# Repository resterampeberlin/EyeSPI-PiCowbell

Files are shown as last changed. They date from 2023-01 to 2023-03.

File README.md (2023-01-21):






              
# Purpose

# Credits

This open source code project is has been proudfully produced in Berlin (and other places around the globe) by

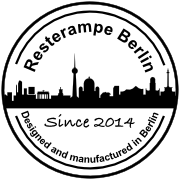
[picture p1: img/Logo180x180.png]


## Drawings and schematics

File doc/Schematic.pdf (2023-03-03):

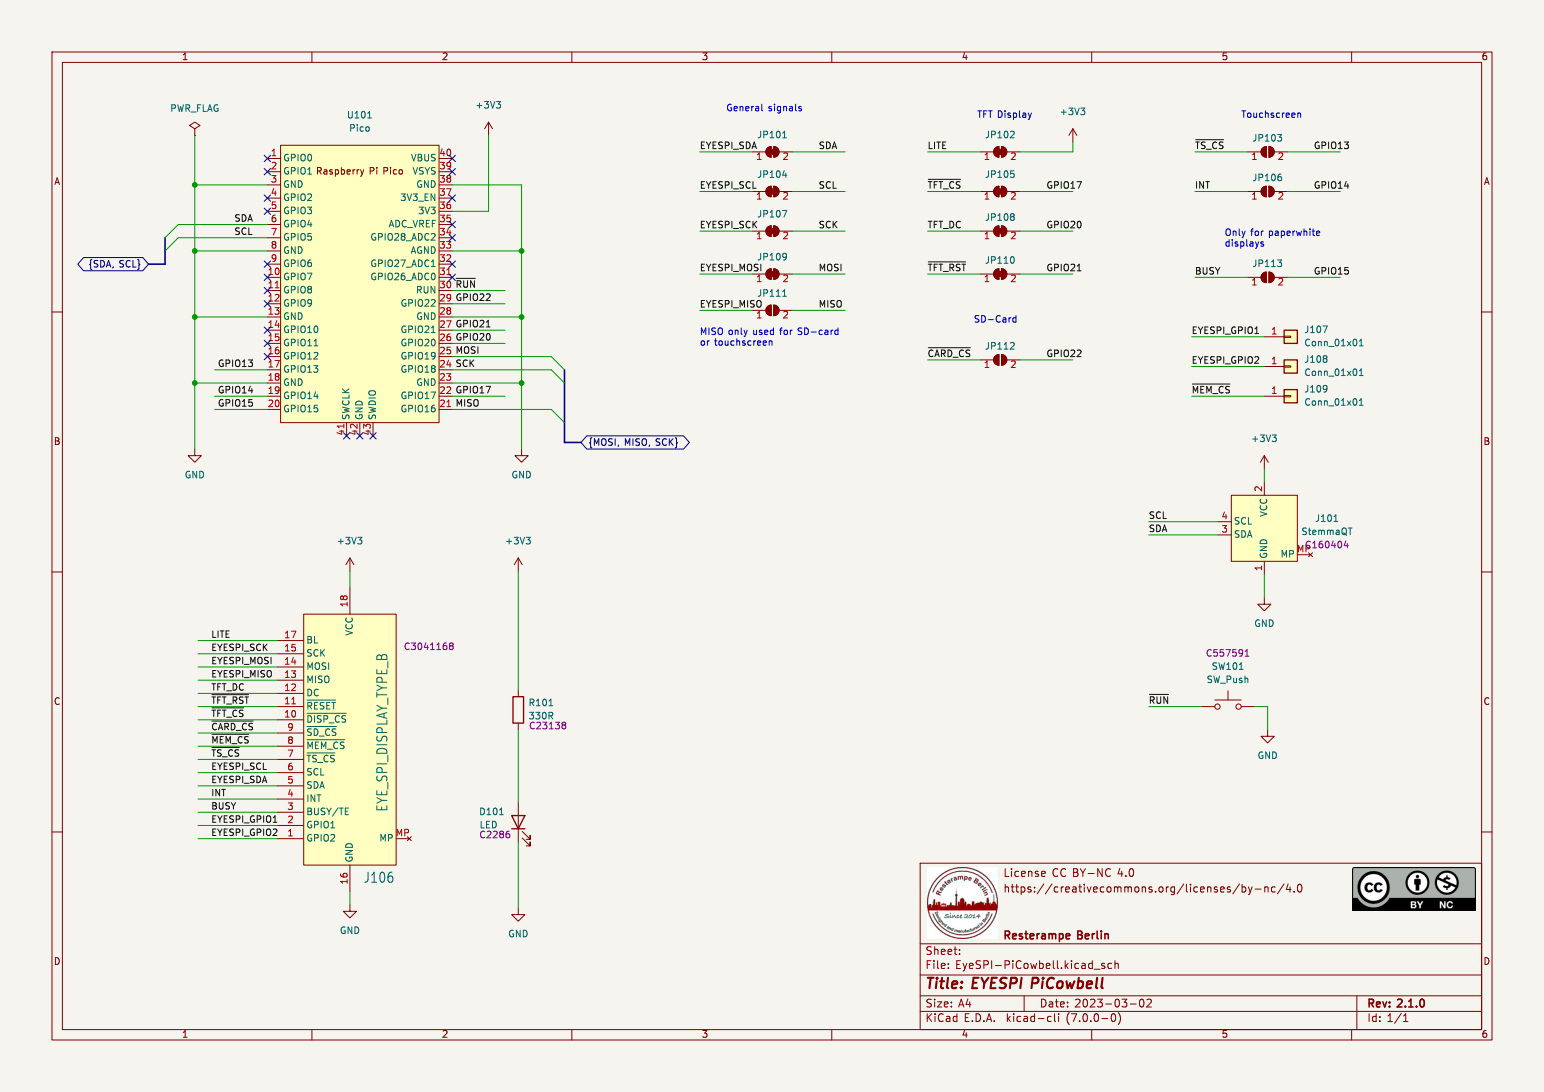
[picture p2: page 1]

2 SDA 3 SCL 4 MP MP

https://creativecommons.org/licenses/by-nc/4.0

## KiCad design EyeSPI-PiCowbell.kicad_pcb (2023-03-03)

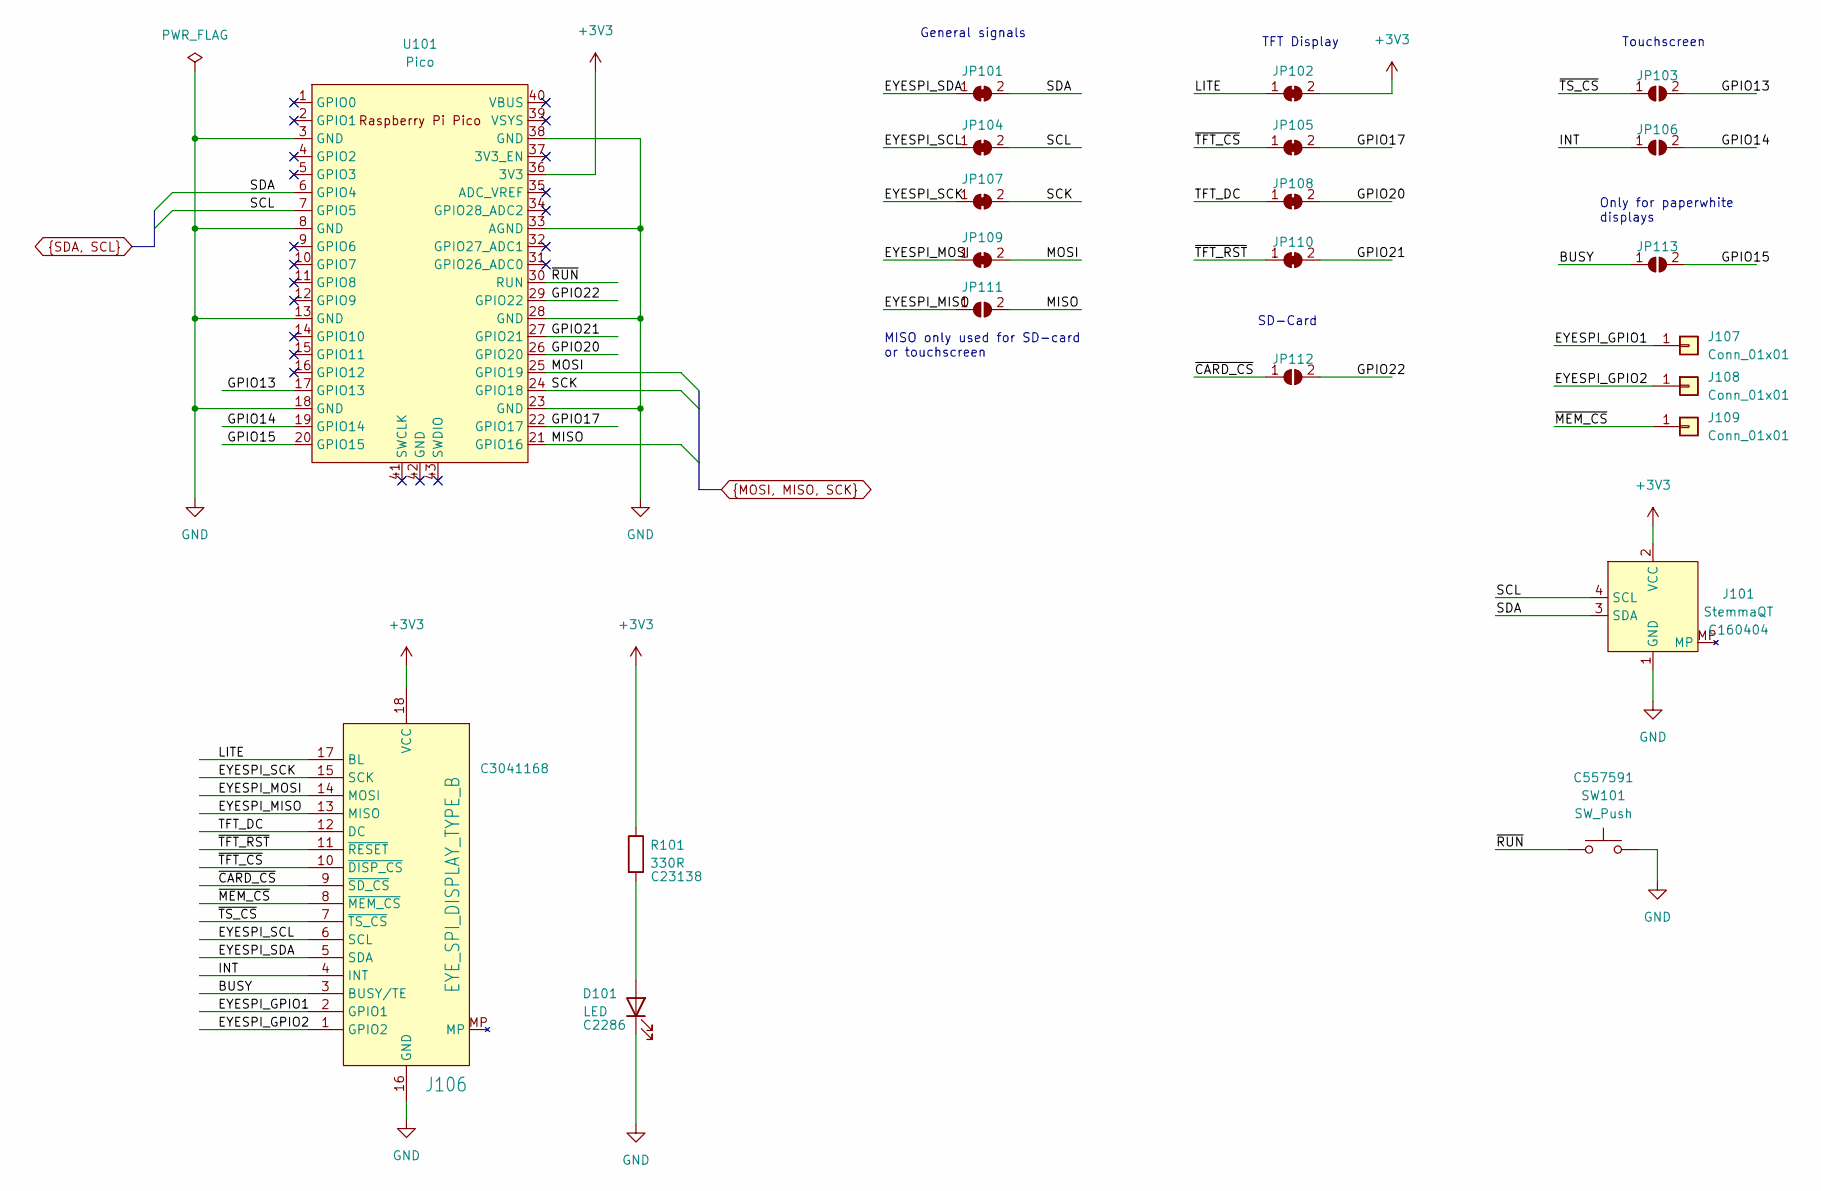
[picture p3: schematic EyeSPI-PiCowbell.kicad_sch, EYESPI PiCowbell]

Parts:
D101: LED; LED_0603_1608Metric_Pad1.05x0.95mm_HandSolder; LCSC C2286
J101: StemmaQT; JST_SH_SM04B-SRSS-TB_1x04-1MP_P1.00mm_Horizontal; LCSC C160404
J106: EYE_SPI_DISPLAY_TYPE_B; Hirose_FH12-18S-0.5SH_1x18-1MP_P0.50mm_Horizontal; LCSC C3041168
J107, J108, J109: Conn_01x01; SolderWire-0.25sqmm_1x01_D0.65mm_OD1.7mm
JP101, JP102, JP104, JP105, JP107, JP108, JP109, JP110: SolderJumper_2_Bridged; SolderJumper-2_P1.3mm_Bridged_Pad1.0x1.5mm
JP103, JP106, JP111, JP112, JP113: SolderJumper_2_Open; SolderJumper-2_P1.3mm_Open_Pad1.0x1.5mm
R101: 330R; R_0603_1608Metric_Pad0.98x0.95mm_HandSolder; LCSC C23138
SW101: SW_Push; Switch_SMD_3.95x2.9mm; LCSC C557591
U101: Pico; RPi_Pico_SMD_TH

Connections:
+3V3: J101.2 (VCC), J106.18 (VCC), JP102.2 (B), R101.1, U101.36 (3V3)
/BUSY: J106.3 (BUSY/TE), JP113.1 (A)
/EYESPI_GPIO1: J106.2 (GPIO1), J107.1
/EYESPI_GPIO2: J106.1 (GPIO2), J108.1
/EYESPI_MISO: J106.13 (MISO), JP111.1 (A)
/EYESPI_MOSI: J106.14 (MOSI), JP109.1 (A)
/EYESPI_SCK: J106.15 (SCK), JP107.1 (A)
/EYESPI_SCL: J106.6 (SCL), JP104.1 (A)
/EYESPI_SDA: J106.5 (SDA), JP101.1 (A)
/GPIO13: JP103.2 (B), U101.17 (GPIO13)
/GPIO14: JP106.2 (B), U101.19 (GPIO14)
/GPIO15: JP113.2 (B), U101.20 (GPIO15)
/GPIO17: JP105.2 (B), U101.22 (GPIO17)
/GPIO20: JP108.2 (B), U101.26 (GPIO20)
/GPIO21: JP110.2 (B), U101.27 (GPIO21)
/GPIO22: JP112.2 (B), U101.29 (GPIO22)
/INT: J106.4 (INT), JP106.1 (A)
/LITE: J106.17 (BL), JP102.1 (A)
/TFT_DC: J106.12 (DC), JP108.1 (A)
/~CARD_CS: J106.9 (~SD_CS), JP112.1 (A)
/~MEM_CS: J106.8 (~MEM_CS), J109.1
/~RUN: SW101.1, U101.30 (RUN)
/~TFT_CS: J106.10 (~DISP_CS), JP105.1 (A)
/~TFT_RST: J106.11 (~RESET), JP110.1 (A)
/~TS_CS: J106.7 (~TS_CS), JP103.1 (A)
GND: D101.1 (K), J101.1 (GND), J106.16 (GND), SW101.2, U101.3 (GND), U101.8 (GND), U101.13 (GND), U101.18 (GND), U101.23 (GND), U101.28 (GND), U101.33 (AGND), U101.38 (GND)
MISO: JP111.2 (B), U101.21 (GPIO16)
MOSI: JP109.2 (B), U101.25 (GPIO19)
unnamed: D101.2 (A), R101.2
SCK: JP107.2 (B), U101.24 (GPIO18)
SCL: J101.4 (SCL), JP104.2 (B), U101.7 (GPIO5)
SDA: J101.3 (SDA), JP101.2 (B), U101.6 (GPIO4)

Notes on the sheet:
General signals
MISO only used for SD-card or touchscreen
Touchscreen
TFT Display
Only for paperwhite displays
SD-Card

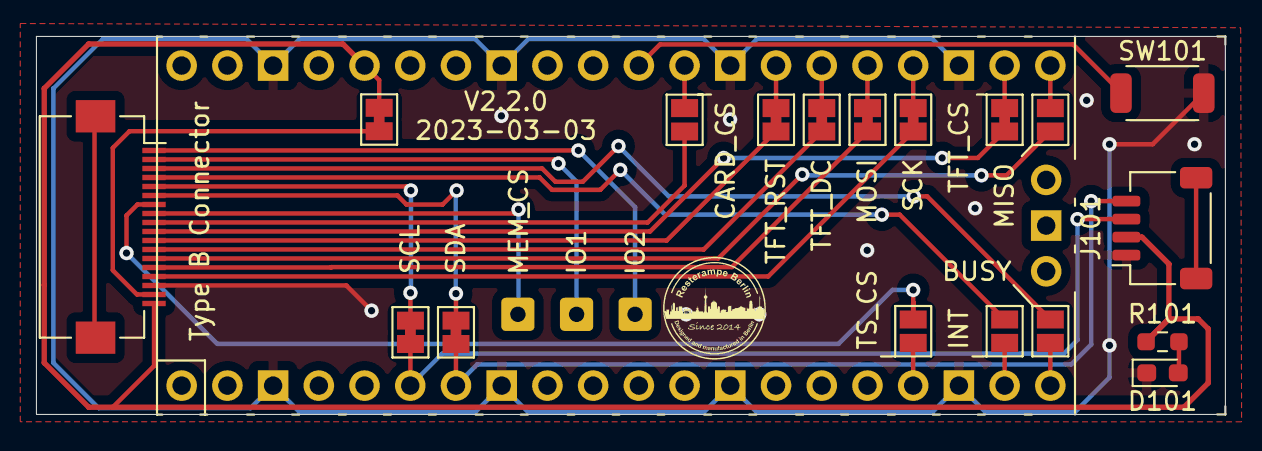
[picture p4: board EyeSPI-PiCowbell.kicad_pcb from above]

Board: 2 copper layers, 66.1 x 21.0 mm, 22 parts (1 on the bottom side), 32 nets.

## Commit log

2023-01-17 Initial version
    [EyeSPI-PiCowbell.kicad_pcb, EyeSPI-PiCowbell.kicad_sch]
2023-02-09 Closes #1 #2 #3
    [EyeSPI-PiCowbell.kicad_pcb, EyeSPI-PiCowbell.kicad_sch]
2023-03-02 Closed #4 update to KiCad 7
    [EyeSPI-PiCowbell-CuBottom 2.gbr, EyeSPI-PiCowbell-CuTop 2.gbr, EyeSPI-PiCowbell-EdgeCuts 2.gbr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]
2023-03-03 Placed FPC connector outside Pico
    [EyeSPI-PiCowbell.kicad_pcb]

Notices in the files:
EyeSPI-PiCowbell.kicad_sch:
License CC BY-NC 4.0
